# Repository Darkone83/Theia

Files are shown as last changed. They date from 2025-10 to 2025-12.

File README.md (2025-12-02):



<div align=center>
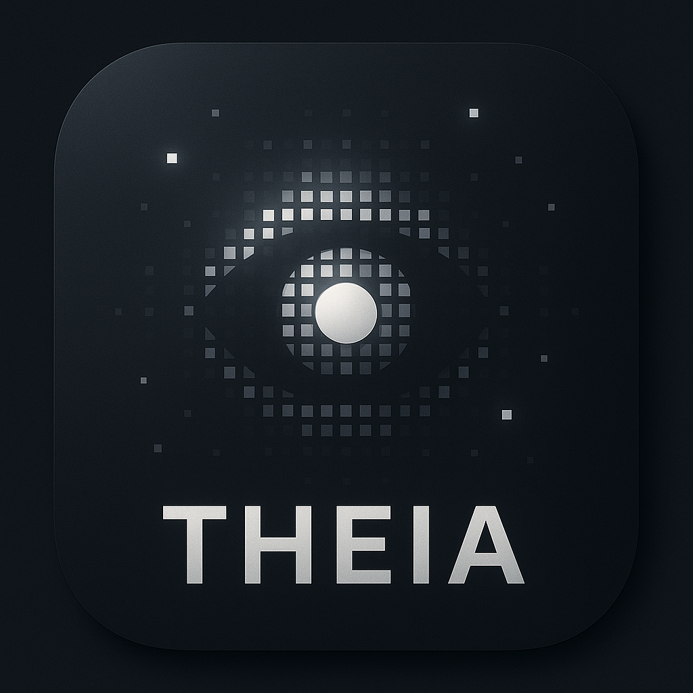
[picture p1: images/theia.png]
  

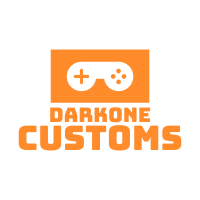
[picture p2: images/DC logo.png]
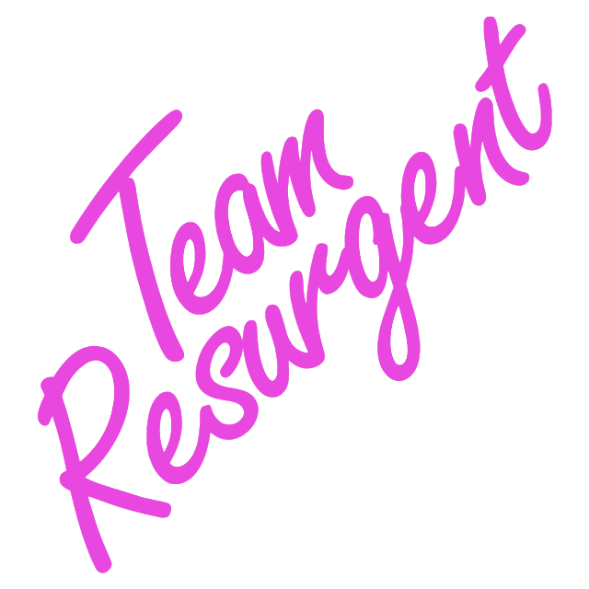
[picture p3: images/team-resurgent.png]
  
</div>

# Theia – OLED Web Emulator for Original Xbox

A Wi-Fi enabled ESP32-S3 emulator for the Xbox LCD display output.

## Overview

Theia is a lightweight firmware for the ESP32-S3 that emulates the Original Xbox 20x4 OLED/HD44780 display. It provides a browser-based LCD viewer, Wi-Fi setup portal, OTA firmware updates, and UDP/SSE LCD state streaming for PC or Mobile apps.

## Features

### Wi-Fi Setup Portal
- Connect to Wi-Fi
- Forget or update credentials
- Auto portal mode when no credentials are saved

### 20x4 OLED / LCD Emulation
- Emulates a US2066-compatible display at I2C address 0x3C
- Supports HD44780 commands and data
- Tracks cursor and row content
- Can be toggled on or off at runtime

### Web-Based LCD Viewer
Live LCD preview available at:
  /emu

JSON snapshot available at:

  /emu/state

### OTA Firmware Updates
Upload new firmware (.bin) at:

  /ota

### RGB Status LED
Indicates:
- Booting
- Wi-Fi connected
- Portal mode
- Wi-Fi failure
- UDP transmit activity

---

Download on the App Store (https://apps.apple.com/us/app/theia-oled-viewer/id6755984567)

## Purchase:

OLED Emulator module: Darkone Customs (coming soon!)

OLED kit: Dakrone Customs (coming soon!)

---

## Compiling the Firmware

1. Install **Arduino IDE 2.x**).
2. Install the **ESP32 board package**:
   - Arduino: Boards Manager → search for "esp32" → install `esp32 by Espressif Systems`
   - PlatformIO: Use the `esp32-s3` platform
3. Select the correct board:
   - `ESP32S3 Dev Module` (or your S3 variant)
4. Set the USB mode:
   - Tools → USB Mode → USB-CDC On Boot: **Enabled**
5. Open the `OLED_EMU.ino`, or `OLED_EMU_US2066.ino` file.
6. Ensure required libraries are installed:
   - ESPAsyncWebServer  
   - AsyncTCP  
   - ArduinoJson
7. Connect your ESP32-S3 board via USB.
8. Click **Upload** to compile and flash the firmware.

If compilation fails, verify the board package version and that ESPAsyncWebServer is the S3-compatible version.

---

## Hardware Installation

Transmitter:

Its recommented to wire directly to the LPC if your XBOX and to keep the wire runs as short as possible

| Pin | Transmiter | XBOX LPC |
|-----|---|---|
|  1  | 5V | 5V Pin 6 |
|  2  | GND | GND Pin 2 or 12 |
|  3  | 3.3V | 3.3V Pin 9 or 13 |
|  4  | SDA | SDA Pin 14 |
|  5  | SCL | SCL Pin 13 |

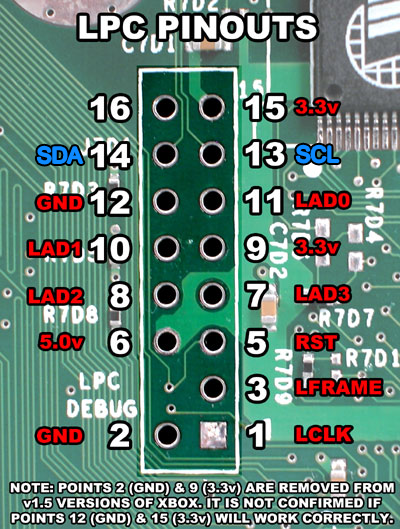
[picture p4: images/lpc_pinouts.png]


Reciever:

**Notes:** IF getting your OWN PCB's made select 1.0mm thickness for the US2066 backpack; otherwise, you may have fitment issues. This os only compatable with the NewHaven Display:  NHD-0420CW

Solder your backpack to the display, then connect 5V and GND to the controller port

When inserting into the case please take note of the TPU spacer placement

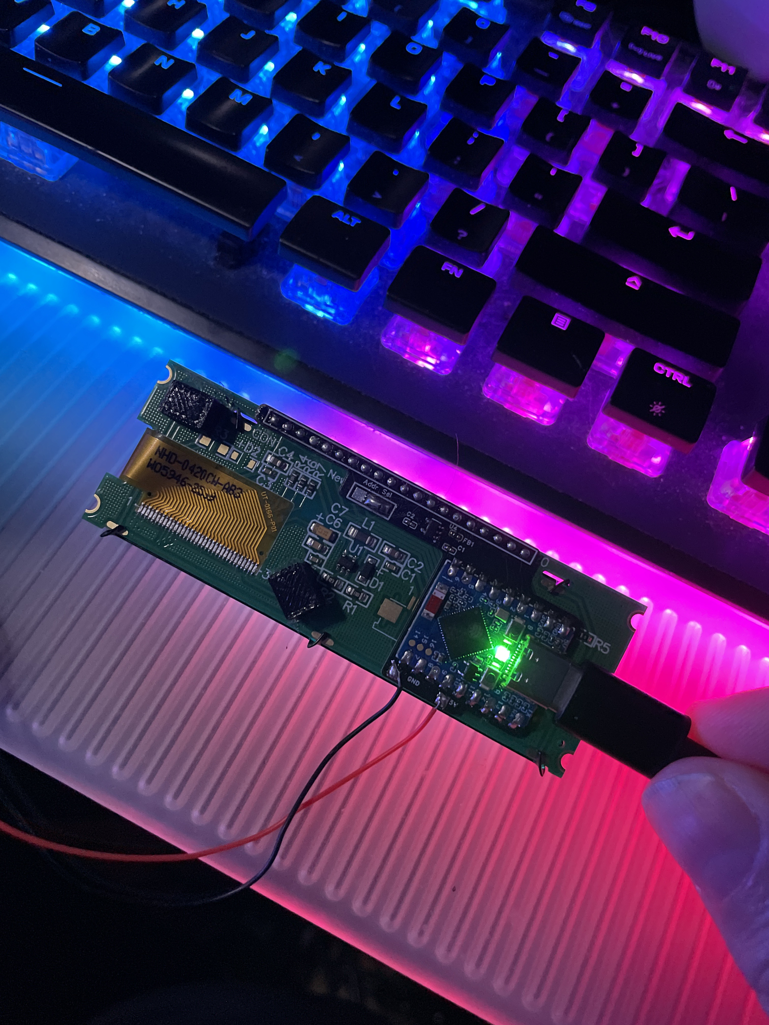
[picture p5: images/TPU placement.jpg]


## Getting Started

1. Flash the ESP32-S3 with the firmware.
2. Power the device. It starts in setup mode if Wi-Fi is not configured.
3. Connect to the access point:
   Type D OLED EMU Setup
4. Open a browser and go to:
   http://oledemu.local, or http://192.168.4.1 for the Transmitter, for the Receiver go to: http://oledemurec.local, ot http://192.168.4.1
5. Save Wi-Fi credentials.
6. After connecting:
   Web Emulator: http://oledemu.local/emu
   JSON State:   http://oledemu.local/emu/state
   OTA Update:   http://oledemu.local/ota

### XBOX Settings

PrometheOS:

Select SMBUS, HD47880 and set address to 0x3C (all other settings can be left alone)

Cerbios:

Select SMBUS, HD47880 and set address to 0x3C (all other settings can be left alone)

XBMC4Gamers:

Select SMBUS, HD47880 and set address to 0x3C (all other settings can be left alone)

## UDP Output

LCD state is broadcast as JSON over UDP on port 35182 following the Type-D viewer format.

## Compatibility

- Original Xbox (all revisions)
- PrometheOS / HD44780 LCD systems
- Type-D Viewer (PC)
- Theia (iOS / Android)

## Known Good Boards

- ESP32-S3 DevKit
- Waveshare ESP32-S3 LCD boards
- Standard S3 Mini modules

## Credits

Developed by Darkone83 / Team Resurgent.

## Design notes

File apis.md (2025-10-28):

# Theia OLED Emulator — APIs

This document lists the public C++ APIs and HTTP/UDP interfaces exposed by the firmware modules present in the provided sources (`lcd_monitor`, `web_emu`, `wifimgr`, `led_stat`).

---

## Module: `lcd_monitor`

### Purpose
Emulates a US2066/HD44780-compatible **20×4** OLED at I²C address **0x3C**, tracks DDRAM/cursor state, and broadcasts snapshots of the screen over UDP as JSON.

### C++ API
```cpp
namespace LCDMonitor {
  void begin(int sda_pin, int scl_pin);
  void loop();

  void broadcastDisplayState(bool force = false);

  // Accessors / controls
  const LCDState& getDisplayState();
  void setEmulatorEnabled(bool enabled);
  bool isEmulatorEnabled();

  // Lifecycle helpers (present for future use)
  bool startI2CSniffer();
  void stopI2CSniffer();
  bool captureI2CTraffic();

  // Hooks (present but no-op in current build)
  struct I2CTransaction { uint8_t address; uint8_t data[32]; uint8_t length; uint32_t timestamp_ms; bool is_write; };
  void processI2CTransaction(const I2CTransaction& tx);
  void decodeLCDCommand(uint8_t addr, const uint8_t* data, uint8_t len);
}
```

### Key type
```cpp
struct LCDState {
  bool display_on, cursor_on, blink_on;
  uint8_t cursor_row, cursor_col;     // 0..3, 0..19
  char rows[4][21];                   // 20 chars + NUL
  uint8_t  detected_addr;             // typically 0x3C
  const char* controller_type;        // e.g., "US2066"
  bool initialized;
  uint32_t last_update_ms, packet_count;
};
```

### UDP Broadcast
- **Address**: `255.255.255.255` (broadcast)
- **Port**: `LCD_MONITOR_UDP_PORT` (constant in header; 35182 in current build)
- **Payload**: JSON (ArduinoJson-serialized), schema:
```json
{
  "type": "lcd20x4",
  "mode": "US2066",
  "addr": "0x3C",
  "disp": true,
  "cur": false,
  "blink": false,
  "cursor": { "r": 0, "c": 0 },
  "rows": [
    "Theia OLED Emulator",
    "Code:   Darkone83   ",
    "Team Resurgent      ",
    "(c) 2025            "
  ]
}
```
Notes:
- `rows` is always **4 strings**, each padded/truncated to **20** printable ASCII characters.
- A heartbeat and a short boot **burst** are emitted; otherwise updates are sent on content change (state hash).

---

## Module: `web_emu`

### Purpose
Serves the in-browser OLED emulator and exposes a JSON snapshot endpoint and an **SSE** stream for live updates.

### C++ API
```cpp
namespace WebEmu {
  void begin();
  void loop();
}
```

### HTTP Endpoints
- **GET `/emu`** — Web UI (HTML/JS/CSS).
- **GET `/emu/state`** — Current display state as JSON (subset of UDP schema; includes `type`, `disp`, `cur`, `blink`, `cursor`, `rows`).  
  Example:
  ```json
  {
    "type":"lcd20x4",
    "disp":true, "cur":false, "blink":false,
    "cursor":{"r":0,"c":0},
    "rows":["Theia OLED Emulator","Code:   Darkone83   ","Team Resurgent      ","(c) 2025            "]
  }
  ```
- **SSE `/emu/events`** — Server-Sent Events stream.  
  - Event `message`: payload is the same JSON snapshot as `/emu/state`.
  - Periodic keep-alives (`event: ka`) when idle.

### Client Notes
- UI offers **Skin**, **Pixel mode**, **Contrast** controls. It fetches `/emu/state` on load and subscribes to `/emu/events` for updates.

---

## Module: `wifimgr`

### Purpose
Captive-portal style Wi‑Fi provisioning (AP+STA), storing credentials in NVS, plus OTA upload and LCD emulator toggles.

### C++ API
```cpp
namespace WiFiMgr {
  AsyncWebServer& getServer();
  void begin();
  void loop();
  void restartPortal();
  void forgetWiFi();
  bool isConnected();
  String getStatus();
}
```

### Captive-Portal redirects
The following GET routes redirect to `/`:
```
/generate_204
/hotspot-detect.html
/redirect
/ncsi.txt
/captiveportal
```

### Wi‑Fi & Control Endpoints
- **GET `/`** — Portal page (HTML) with scan/connect UI and emulator on/off switch.
- **GET `/status`** — Text status string of current connection or portal mode.
- **GET `/scan`** — Returns `["ssid1","ssid2",...]` (deduplicated, sorted). Triggers background scan as needed.
- **GET `/connect?ssid=...&pass=...`** — Saves credentials and begins STA connection.
- **POST `/save`** — JSON body `{"ssid":"...","pass":"..."}`. Saves and begins STA connection.
- **GET `/forget`** — Clears saved credentials and returns to portal mode.
- **GET `/debug/forget`** — Same as `/forget` with extra serial logs.
- **POST `/reboot`** — Reboots the device after a short delay.

### LCD Emulator Control
- **GET `/lcd/state`** — `{ "enabled": true|false }`
- **ANY `/lcd/enable`** — Enables the I²C OLED emulator.
- **ANY `/lcd/disable`** — Disables the I²C OLED emulator (releases I²C slave).

### OTA
- **GET `/ota`** — Minimal OTA upload page (HTML with JS progress).
- **POST `/update`** — Multipart form field `firmware` (binary). On success responds `200 OK`. (No auto‑restart; use `/reboot`.)

---

## Module: `led_stat`

### Purpose
Single NeoPixel RGB LED indicating device status.

### C++ API
```cpp
enum class LedStatus { Booting, Portal, WifiConnected, WifiFailed, UdpTransmit };

namespace LedStat {
  void begin();
  void setStatus(LedStatus status);
  void loop();
}
```

### Behavior (defaults)
- `Booting` → solid white
- `Portal` → blinking purple
- `WifiConnected` → solid green
- `WifiFailed` → solid red
- `UdpTransmit` → brief activity indication (if used)

---

## Integration Cheatsheet

### Listen for screen updates (PC/receiver)
- Bind UDP socket to **port 35182**.
- Parse the JSON payload (see schema above).

### Browser client
- Initial snapshot: `GET /emu/state`
- Live updates: `EventSource('/emu/events')`

### Toggle emulator
```
GET /lcd/state
ANY /lcd/enable
ANY /lcd/disable
```

### Provision Wi‑Fi
```
GET  /scan
POST /save        body: {"ssid":"<ssid>","pass":"<pass>"}
GET  /connect?ssid=<ssid>&pass=<pass>
GET  /forget
GET  /status
```

### OTA
```
GET  /ota
POST /update   (multipart form data: firmware=<bin>)
POST /reboot
```

---

## Notes
- The emulator sanitizes non-printable characters to space (0x20) for UDP/HTTP emits.
- A small boot **burst** and periodic **keep-alives** ensure downstream listeners initialize correctly even if the screen is static.

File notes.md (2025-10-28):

# Notes

## US2066 PCB

---

Should be made @ 1.0mm to fit proeprly in the case

---

## STLs

---

TPU space is HIGHLY recommened to be made in TPU with 30% infill. Check images folder for approximate placement

---

## Required Arduino libraties

---

ArduinoJSON
ESPAsyncWebServer

---

## Arduino Boards

---

esp32 (3.3.2)

---

## Board Config

---

Parition: Default 4mb with spiffs
CDC: Enabled
Flash size: 4mb

---

## Notes

---

Tested with the WaveShare ESP32 zero and clone boards on aliexpress

---

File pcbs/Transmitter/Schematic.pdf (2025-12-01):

GND

GND

5V

XSCL
XSDA
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
XBSMB

ZX-SH1.0-5PWT

3.3V

GND

5V

XSCL | XSDA

5V 1
GND 2
3V3 3
IO1 4
IO2 5
IO3 6
IO4 7
IO5 8
IO6 9

# IO7 10 IO8 11 IO9 12 IO10 13 IO11 14 IO12 15 IO13 16 RX 17 TX 18

U1

ESP32-S3-Zero

3.3V

5V | 5VEN
GND
1uFC1 | C2 1uF

R1
100k
GND | GND

GND

VIN 1
GND 2
ON 3 | CT 4

QOD 5

VOUT 6

U2

TPS22918DBVR

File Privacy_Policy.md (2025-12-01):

Theia – Privacy Policy

Last updated: 11/27/2025

---

Overview

---

Theia respects your privacy.
This app does not collect, store, transmit, or share any personal data of any kind.

Information We Do Not Collect

Theia does not collect or process:

Personal information

Usage data

Diagnostics data

Location data

Contact information

Identifiers

Photos, media, or files

Device analytics

Advertiser data

Any data linked or not linked to you

Data Handling

The app performs all operations locally on your device.

No data is sent to external servers.

No third-party SDKs, analytics, tracking, or advertising frameworks are used.

---

Children’s Privacy

Because Theia collects no data, it is safe for users of all ages.
No information is knowingly collected from children.

---

Third-Party Access

Theia does not share any information with third parties because no information is collected at all.

---

Changes to This Policy

If the privacy policy is ever updated, changes will be posted within the app and on the associated website or repository. The app will continue to collect no data unless explicitly stated in a future revision.

---

Contact

If you have questions about this Privacy Policy, you can contact us:

Darkone Customs

Email: darkonecustoms@gmail.com

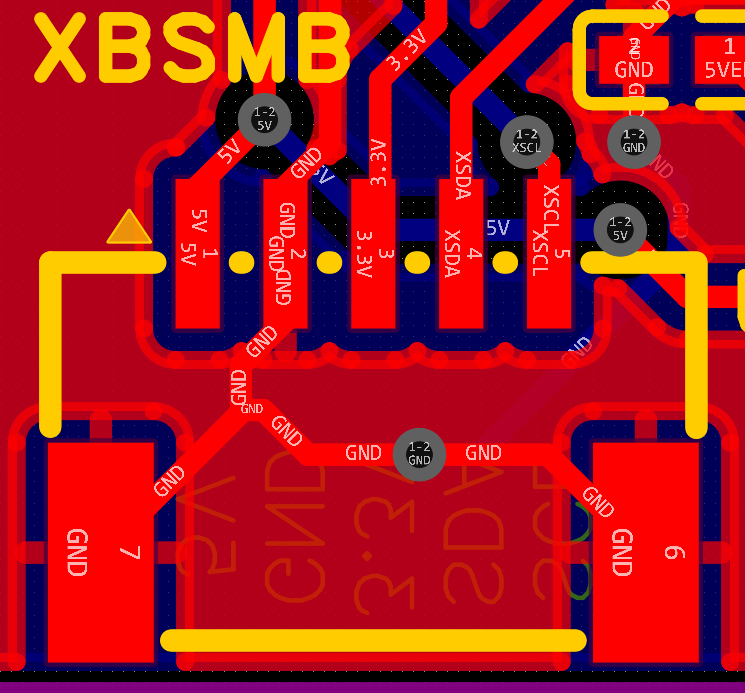
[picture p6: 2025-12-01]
images/pins.png

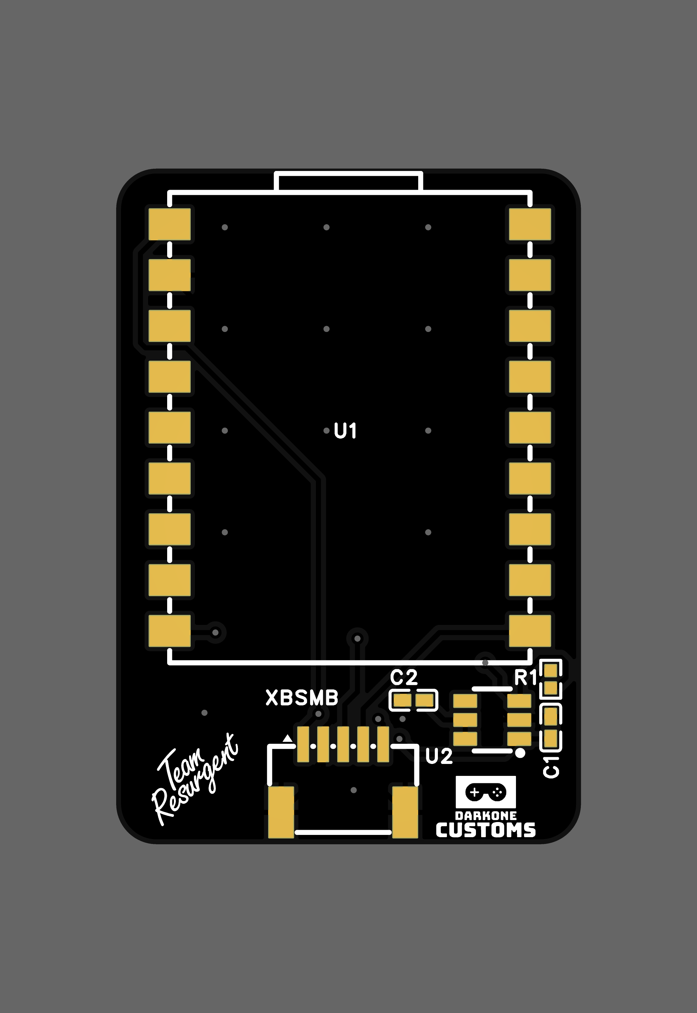
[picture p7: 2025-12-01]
images/2D Front Transmitter.png

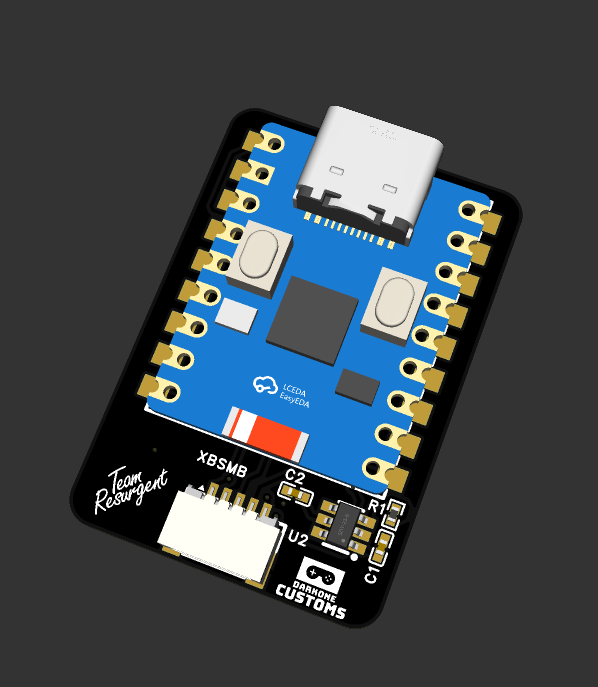
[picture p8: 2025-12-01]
images/3D Front Transmitter.png

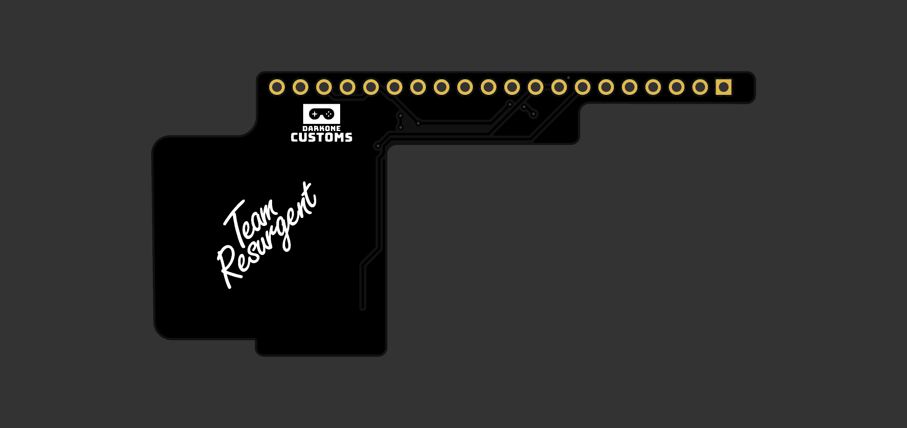
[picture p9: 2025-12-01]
images/2D Back US2066 Backpack.png

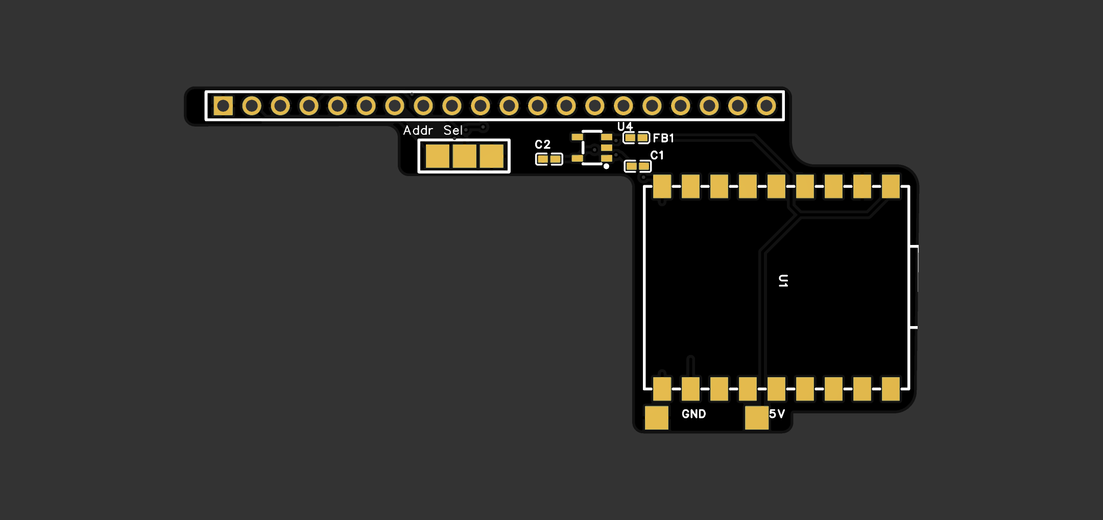
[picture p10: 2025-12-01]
images/2D Front US2066 Backpack.png

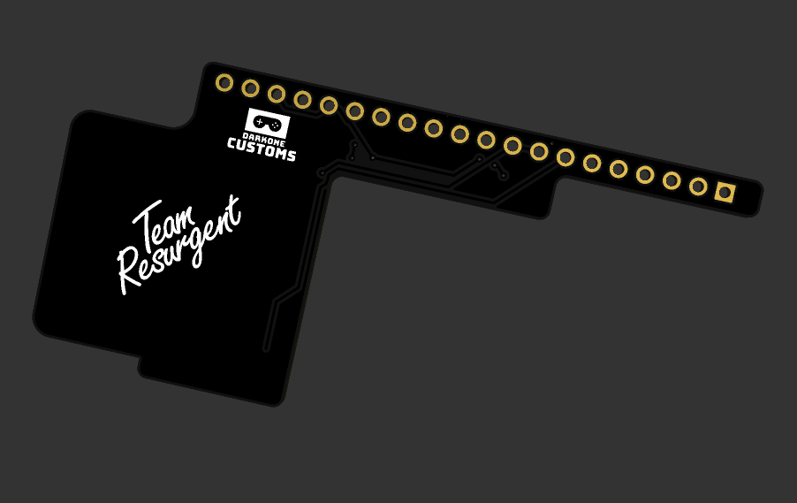
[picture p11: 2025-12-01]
images/3D Back US2066 Backpack.png

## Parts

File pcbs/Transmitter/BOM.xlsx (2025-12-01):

No. | Quantity | Comment | Designator | Footprint | Value | Manufacturer Part | Manufacturer | Supplier Part | Supplier
1 | 2 | 1uF | C1,C2 | C0402 | 1uF | CL05A105KO5NNNC | SAMSUNG(三星) | C29266 | LCSC
2 | 1 | 100kΩ | R1 | R0402 | 100kΩ | RC0402FR-07100KL | YAGEO(国巨) | C60491 | LCSC
3 | 1 | ESP32-S3-Zero | U1 | COMM-SMD_18P-P2.54-L23.5-W18.0-TL |  | ESP32-S3-Zero |  | C9900152785 | LCSC
4 | 1 | TPS22918DBVR | U2 | SOT-23-6_L2.9-W1.6-P0.95-LS2.8-BR |  | TPS22918DBVR | TI(德州仪器) | C131941 | LCSC
5 | 1 | ZX-SH1.0-5PWT | XBSMB | CONN-SMD_5P-P1.00_MEGASTAR_ZX-SH1.0-5PWT |  | ZX-SH1.0-5PWT | Megastar(兆星) | C7430447 | LCSC

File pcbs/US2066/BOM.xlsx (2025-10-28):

No. | Quantity | Comment | Designator | Footprint | Value | Manufacturer Part | Manufacturer | Supplier Part | Supplier
1 | 5 | Test-Point | 5V,GND,TP1,TP2,TP3 | Test-Point-0.5mm
2 | 2 | 1uF | C1,C2 | C0402 | 1uF | CL05A105KO5NNNC | SAMSUNG(三星) | C29266 | LCSC
3 | 1 | CBM100505U201T | FB1 | L0402 |  | CBM100505U201T | FH(风华) | C394402 | LCSC
4 | 1 | ESP32-S3-Zero | U1 | COMM-SMD_18P-P2.54-L23.5-W18.0-TL |  | ESP32-S3-Zero |  | C9900152785 | LCSC
5 | 1 | XC6227C331MR-G | U4 | SOT-25-5 |  | XC6227C331MR-G | TOREX(特瑞仕) | C216640 | LCSC

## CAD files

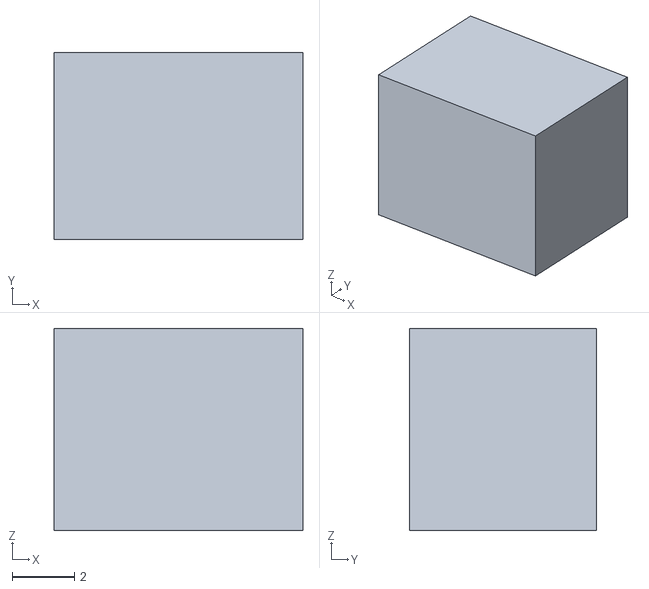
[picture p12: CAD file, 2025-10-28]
STL/TPU Spacer Cube.stl
8.00 x 6.00 x 6.50

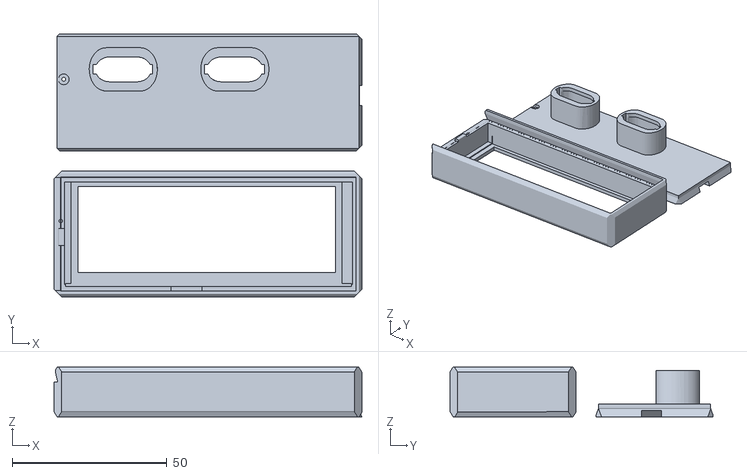
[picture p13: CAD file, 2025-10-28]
STL/US2066 Shell.stl
99.4 x 84.9 x 16.0

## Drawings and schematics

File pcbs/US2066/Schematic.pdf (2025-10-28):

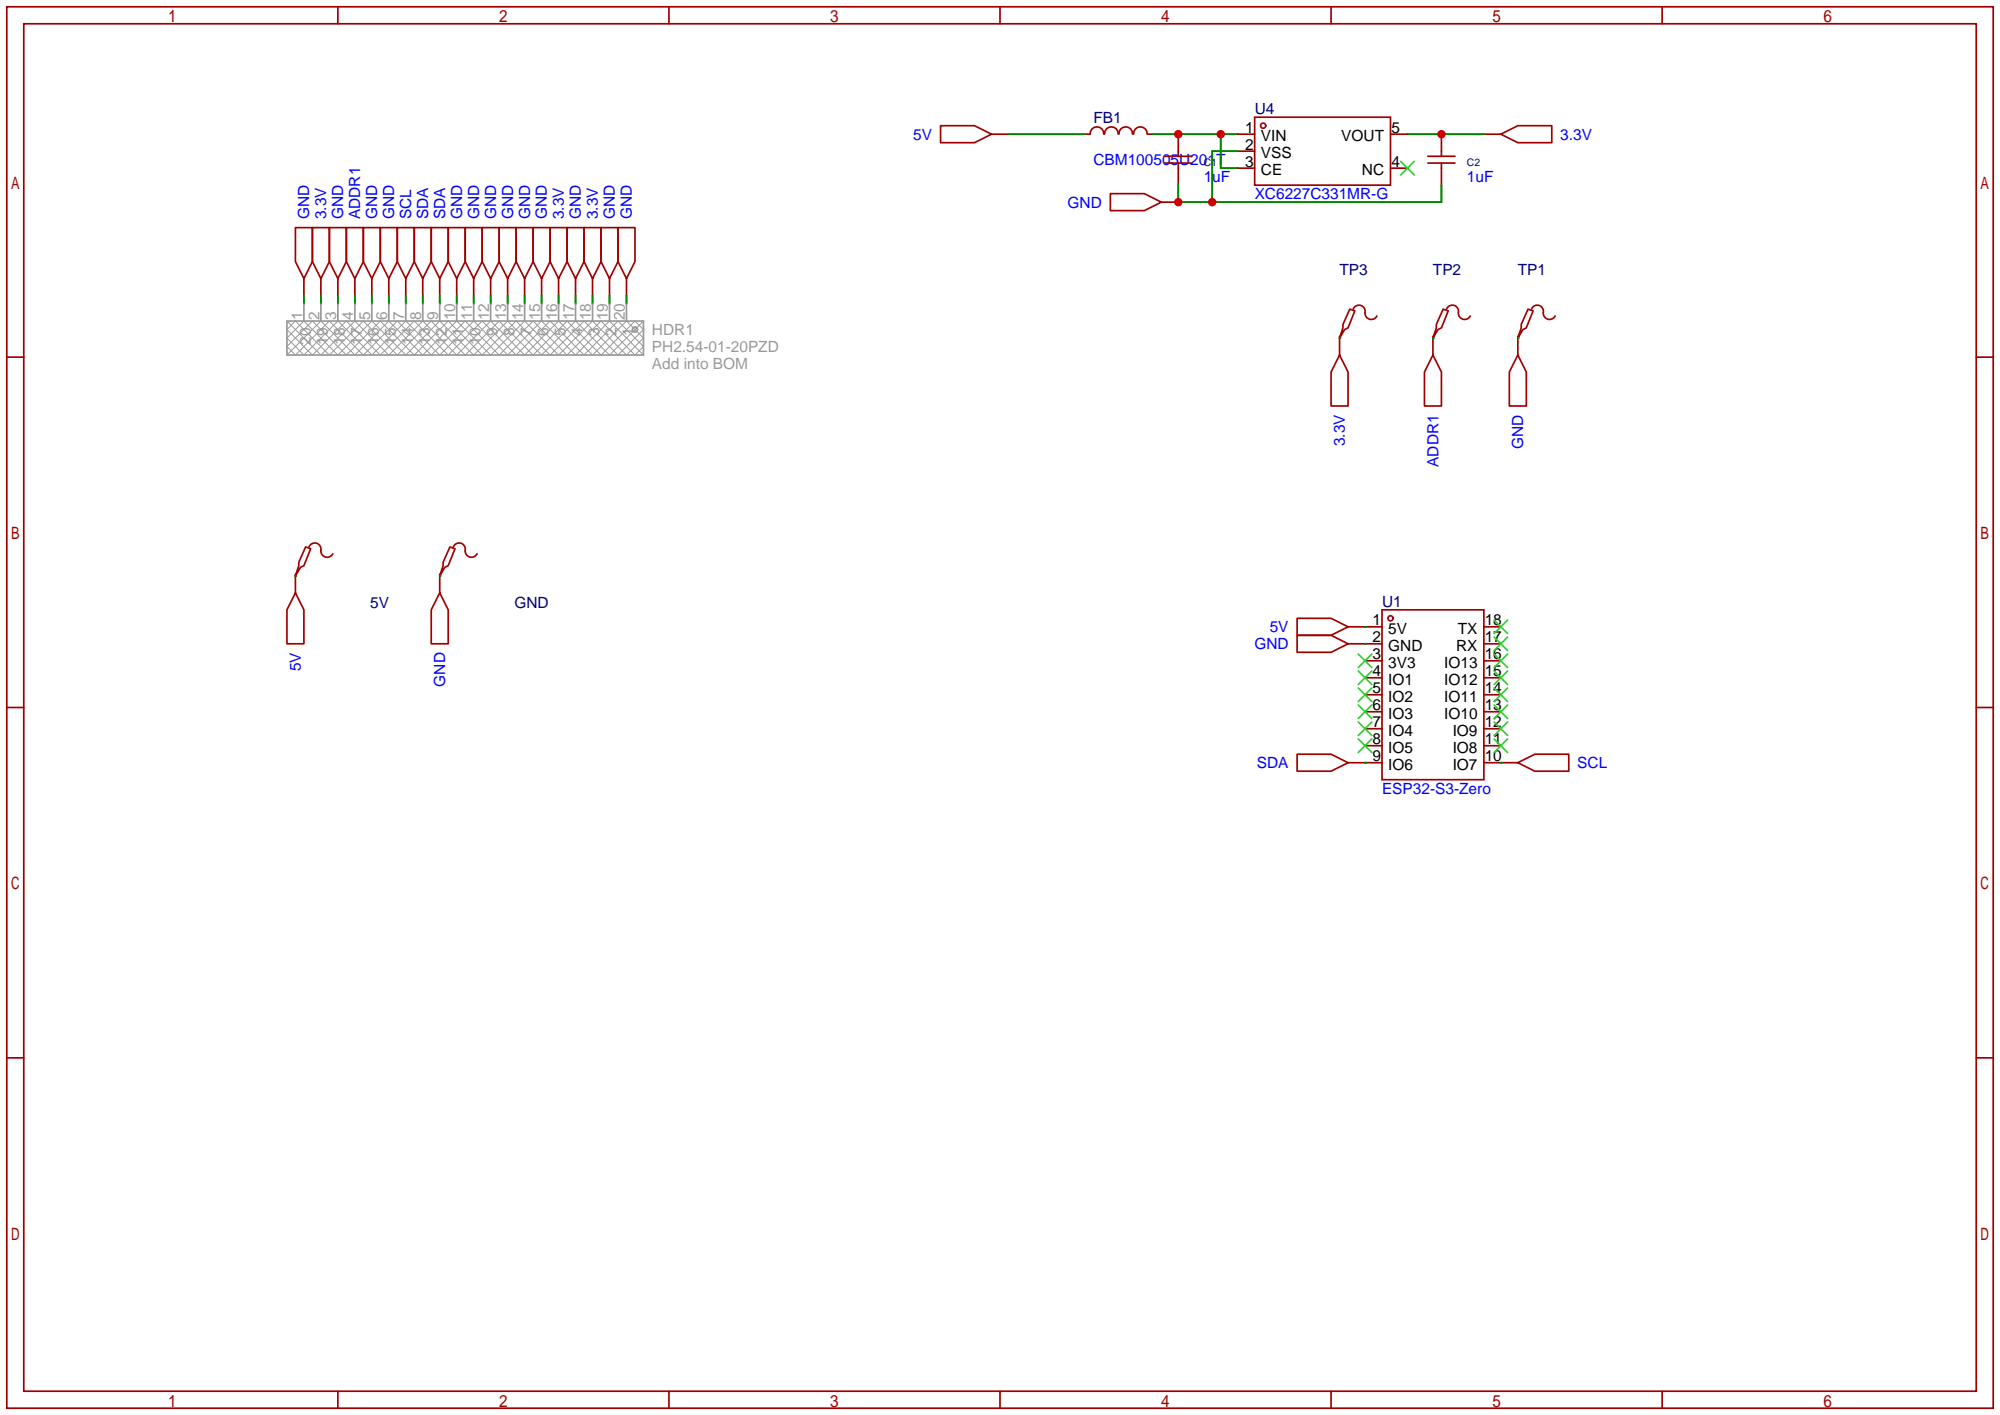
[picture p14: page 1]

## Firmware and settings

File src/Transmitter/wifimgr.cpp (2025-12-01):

#include "wifimgr.h"
#include <WiFi.h>
#include <ESPAsyncWebServer.h>
#include <Preferences.h>
#include <DNSServer.h>
#include "led_stat.h"
#include <vector>
#include "esp_wifi.h"
#include <Update.h> // For OTA
#include "lcd_monitor.h" // <-- for emulator enable/disable

static AsyncWebServer server(80);
namespace WiFiMgr {

static String ssid, password;
static Preferences prefs;
static DNSServer dnsServer;
static std::vector<String> lastScanResults;

enum class State { IDLE, CONNECTING, CONNECTED, PORTAL };
static State state = State::PORTAL;

static int connectAttempts = 0;
static const int maxAttempts = 10;
static unsigned long lastAttempt = 0;
static unsigned long retryDelay = 3000;

AsyncWebServer& getServer() {
    return server;
}

static void setAPConfig() {
    WiFi.softAPConfig(
        IPAddress(192, 168, 4, 1),
        IPAddress(192, 168, 4, 1),
        IPAddress(255, 255, 255, 0)
    );
}

void loadCreds() {
    prefs.begin("wifi", true);
    ssid = prefs.getString("ssid", "");
    password = prefs.getString("pass", "");
    prefs.end();
}

void saveCreds(const String& s, const String& p) {
    prefs.begin("wifi", false);
    prefs.putString("ssid", s);
    prefs.putString("pass", p);
    prefs.end();
}

void clearCreds() {
    prefs.begin("wifi", false);
    prefs.remove("ssid");
    prefs.remove("pass");
    prefs.end();
}

static String htmlSwitch(bool on) {
    String checked = on ? "checked" : "";
    return String() +
        "<label class='switch'>"
        "<input id='emuToggle' type='checkbox' " + checked + " onchange='toggleEmu(this.checked)'>"
        "<span class='slider round'></span>"
        "</label>";
}

void startPortal() {
    WiFi.disconnect(true);
    delay(100);
    setAPConfig();
    WiFi.mode(WIFI_AP_STA);  // AP+STA for S3 (portal)
    delay(100);

    // Use channel 6 for iOS compatibility
    bool apok = WiFi.softAP("Type D OLED EMU Setup", "", 6, 0);
    esp_wifi_set_max_tx_power(20);
    LedStat::setStatus(LedStatus::Portal);
    Serial.printf("[WiFiMgr] softAP result: %d, IP: %s\n", apok, WiFi.softAPIP().toString().c_str());
    delay(200);

    IPAddress apIP = WiFi.softAPIP();
    dnsServer.start(53, "*", apIP);

    server.reset(); // avoid duplicate routes on restart

    // Allow cross-origin (Electron/file:// webviews)
    DefaultHeaders::Instance().addHeader("Access-Control-Allow-Origin", "*");

    server.on("/", HTTP_GET, [](AsyncWebServerRequest *request){
        const bool emuOn = LCDMonitor::isEmulatorEnabled();
        String page = R"rawliteral(
<!DOCTYPE html>
<html>
<head>
    <title>WiFi Setup</title>
    <meta name="viewport" content="width=320,initial-scale=1">
    <style>
        body {background:#111;color:#EEE;font-family:sans-serif;}
        .container {max-width:340px;margin:24px auto;background:#222;padding:2em;border-radius:12px;box-shadow:0 0 16px #0008;}
        input,select,button {width:100%;box-sizing:border-box;margin:.7em 0;padding:.6em;font-size:1.05em;border-radius:8px;border:1px solid #555;background:#111;color:#EEE;}
        .btn-primary {background:#299a2c;color:white;border-color:#299a2c;}
        .btn-danger {background:#a22;color:white;border-color:#a22;}
        .btn-ota {background:#265aa5;color:white;border-color:#265aa5;}
        .btn-web {background:#3b82f6;color:white;border-color:#3b82f6;}
        .status {margin-top:1em;font-size:.95em;}
        label {display:block;margin-top:.5em;margin-bottom:.1em;}
        .row {display:flex;gap:10px;align-items:center;}
        .row > * {flex:1;}
        .pill {display:inline-block;padding:.35em .6em;border-radius:999px;background:#333;border:1px solid #555;font-size:.85em;margin-left:6px;}
        .switch {position: relative; display: inline-block; width: 52px; height: 28px; vertical-align:middle;}
        .switch input {opacity: 0; width: 0; height: 0;}
        .slider {position: absolute; cursor: pointer; top: 0; left: 0; right: 0; bottom: 0; background-color: #555; transition: .2s; border-radius: 28px;}
        .slider:before {position: absolute; content: ""; height: 22px; width: 22px; left: 3px; bottom: 3px; background-color: white; transition: .2s; border-radius:50%;}
        input:checked + .slider {background-color: #299a2c;}
        input:checked + .slider:before {transform: translateX(24px);}
        .section {margin-top:18px;padding-top:12px;border-top:1px dashed #444;}
        .small {font-size:.9em;color:#bbb;}
    </style>
</head>
<body>
    <div class="container">
        <div style="width:100%;text-align:center;margin-bottom:1em">
            <span style="font-size:1.6em;font-weight:bold;">Type D OLED Emulator Setup</span>
        </div>

        <div class="section">
            <div class="row" style="justify-content:space-between">
                <div style="flex:unset"><b>LCD Emulator</b><span id="emuState" class="pill">...</span></div>
                <div style="flex:unset" id="emuSwitchHolder">__EMU_SWITCH__</div>
            </div>
            <div class="small">Toggle the US2066 emulator (I²C slave at 0x3C) on/off without reboot. Disabling releases the I²C bus.</div>
        </div>

        <div class="section">
            <form id="wifiForm" onsubmit="return false;">
                <label>WiFi Network</label>
                <select id="ssidDropdown" style="margin-bottom:1em;">
                    <option value="">Please select a network</option>
                </select>
                <input type="text" id="ssid" placeholder="SSID" style="margin-bottom:1em;">
                <label>Password</label>
                <input type="password" id="pass" placeholder="WiFi Password">
                <div class="row">
                    <button type="button" onclick="save()" class="btn-primary">Connect & Save</button>
                    <button type="button" onclick="forget()" class="btn-danger">Forget WiFi</button>
                </div>
                <div class="row">
                    <button type="button" onclick="window.location='/ota'" class="btn-ota">OTA Update</button>
                    <button type="button" onclick="window.location='/emu'" class="btn-web">Web View</button>
                </div>
                <div class="row">
                    <button type="button" onclick="fetch('/udp/ping',{method:'POST'}).then(r=>r.text()).then(t=>alert(t)).catch(()=>alert('Ping failed'))" class="btn-web">Test UDP Ping</button>
                </div>
            </form>
            <div class="status" id="status">Status: ...</div>
        </div>
    </div>
    <script>
        function setEmuStateTag(on){
            const tag = document.getElementById('emuState');
            tag.textContent = on ? 'ENABLED' : 'DISABLED';
            tag.style.background = on ? '#164b18' : '#4b1616';
            tag.style.borderColor = on ? '#299a2c' : '#a22';
        }
        function fetchEmuState(){
            fetch('/lcd/state').then(r=>r.json()).then(j=>{
                setEmuStateTag(!!j.enabled);
                const toggle = document.getElementById('emuToggle');
                if (toggle) toggle.checked = !!j.enabled;
            }).catch(()=>{});
        }
        function toggleEmu(on){
            fetch(on ? '/lcd/enable' : '/lcd/disable', {method:'POST'})
                .then(()=>fetchEmuState());
        }

        function uniq(arr){ return [...new Set(arr.filter(s=>s && s.trim().length))]; }
        let scanning=false;
        function scan() {
            if (scanning) return; scanning=true;
            fetch('/scan').then(r => r.json()).then(list => {
                list = uniq(list).sort((a,b)=>a.localeCompare(b));
                let dropdown = document.getElementById('ssidDropdown');
                dropdown.innerHTML = '';
                let defaultOpt = document.createElement('option');
                defaultOpt.value = '';
                defaultOpt.text = 'Please select a network';
                dropdown.appendChild(defaultOpt);
                list.forEach(ssid => {
                    let opt = document.createElement('option');
                    opt.value = ssid;
                    opt.text = ssid;
                    dropdown.appendChild(opt);
                });
                dropdown.onchange = function() {
                    document.getElementById('ssid').value = dropdown.value;
                };
            }).catch(() => {
                let dropdown = document.getElementById('ssidDropdown');
                dropdown.innerHTML = '';
                let opt = document.createElement('option');
                opt.value = '';
                opt.text = 'Scan failed';
                dropdown.appendChild(opt);
            }).finally(()=>{ scanning=false; });
        }
        setInterval(scan, 3000);
        window.onload = function(){
            scan();
            fetchEmuState();
        };
        function save() {
            let ssid = document.getElementById('ssid').value;
            let pass = document.getElementById('pass').value;
            fetch('/save', {
                method: 'POST',
                headers: {'Content-Type': 'application/json'},
                body: JSON.stringify({ssid:ssid,pass:pass})
            }).then(r => r.text()).then(t => {
                document.getElementById('status').innerText = t;
            });
        }
        function forget() {
            fetch('/forget').then(r => r.text()).then(t => {
                document.getElementById('status').innerText = t;
                document.getElementById('ssid').value = '';
                document.getElementById('pass').value = '';
            });
        }
        document.getElementById('emuSwitchHolder').innerHTML = `)rawliteral";
        page += htmlSwitch(emuOn);
        page += R"rawliteral(`.replace('__EMU_SWITCH__','');
    </script>
</body>
</html>
        )rawliteral";
        request->send(200, "text/html", page);
    });

    // === OTA PAGE ===
    server.on("/ota", HTTP_GET, [](AsyncWebServerRequest *request){
        String page = R"rawliteral(
<!DOCTYPE html>
<html>
<head>
    <title>OTA Update</title>
    <meta name="viewport" content="width=320,initial-scale=1">
    <style>
        body {background:#111;color:#EEE;font-family:sans-serif;}
        .container {max-width:360px;margin:24px auto;background:#222;padding:2em;border-radius:12px;box-shadow:0 0 16px #0008;}
        input[type=file],button {width:100%;box-sizing:border-box;margin:.7em 0;padding:.6em;font-size:1.05em;border-radius:8px;border:1px solid #555;background:#111;color:#EEE;}
        .btn {background:#265aa5;color:white;border-color:#265aa5;}
        .status {margin-top:1em;font-size:.95em;}
        .barWrap {background:#111;border:1px solid #555;border-radius:8px;overflow:hidden;height:16px;margin-top:.5em}
        .bar {height:100%;width:0%;}
    </style>
</head>
<body>
    <div class="container">
        <h2>OTA Update</h2>
        <input id="fw" type="file" accept=".bin">
        <button class="btn" onclick="doUpload()">Upload & Flash</button>
        <div class="barWrap"><div id="bar" class="bar"></div></div>
        <div id="pct" class="status">0%</div>
        <div id="otaStatus" class="status"></div>
        <div class="row">
            <button class="btn" onclick="window.location='/'" style="margin-top:14px;">Back to WiFi Setup</button>
            <button class="btn" onclick="fetch('/reboot',{method:'POST'}).then(()=>{document.getElementById('otaStatus').innerText='Rebooting...';})" style="margin-top:14px;">Reboot Now</button>
        </div>
    </div>
    <script>
        function doUpload(){
            const f = document.getElementById('fw').files[0];
            if(!f){ alert('Choose a .bin first'); return; }
            const xhr = new XMLHttpRequest();
            xhr.open('POST','/update',true);
            xhr.upload.onprogress = (e)=>{
                if(e.lengthComputable){
                    const p = Math.round((e.loaded/e.total)*100);
                    document.getElementById('bar').style.width = p + '%';
                    document.getElementById('bar').style.background = p>=100 ? '#299a2c' : '#265aa5';
                    document.getElementById('pct').innerText = p + '%';
                }
            };
            xhr.onreadystatechange = ()=>{
                if(xhr.readyState===4){
                    if(xhr.status===200){
                        document.getElementById('otaStatus').innerText = 'Upload complete. Flash OK.';
                    } else {
                        document.getElementById('otaStatus').innerText = 'Upload finished with status ' + xhr.status;
                    }
                }
            };
            const form = new FormData();
            form.append('firmware', f, f.name);
            xhr.send(form);
        }
    </script>
</body>
</html>
        )rawliteral";
        request->send(200, "text/html", page);
    });

    // === OTA FIRMWARE UPLOAD HANDLER (chunked) ===
    server.on("/update", HTTP_POST,
        [](AsyncWebServerRequest *request){},
        [](AsyncWebServerRequest *request, String filename, size_t index, uint8_t *data, size_t len, bool final) {
            static bool updateError = false;
            if (!index) {
                Serial.printf("[OTA] Start update: %s (streaming)\n", filename.c_str());
                updateError = false;
                if (!Update.begin(UPDATE_SIZE_UNKNOWN)) {
                    Update.printError(Serial);
                    updateError = true;
                }
            }
            if (!updateError && !Update.hasError()) {
                size_t written = Update.write(data, len);
                if (written != len) {
                    Update.printError(Serial);
                    updateError = true;
                }
            }
            if (final) {
                bool ok = (!updateError && Update.end(true));
                if (!ok) {
                    Update.printError(Serial);
                    request->send(200, "text/plain", "Update processed, but reported an error: " + String(Update.errorString()));
                } else {
                    request->send(200, "text/plain", "OK");
                    Serial.println("[OTA] Update success (no auto-restart). Use /reboot or power-cycle.");
                }
            }
        }
    );

    // Explicit reboot endpoint
    server.on("/reboot", HTTP_POST, [](AsyncWebServerRequest *request){
        request->send(200, "text/plain", "Rebooting...");
        Serial.println("[WiFiMgr] Reboot requested via /reboot");
        delay(200);
        ESP.restart();
    });

    // Status
    server.on("/status", HTTP_GET, [](AsyncWebServerRequest *request){
        String stat;
        if (WiFi.status() == WL_CONNECTED)
            stat = "Connected to " + WiFi.SSID() + " - IP: " + WiFi.localIP().toString();
        else if (state == State::CONNECTING)
            stat = "Connecting to " + ssid + "...";
        else
            stat = "In portal mode";
        request->send(200, "text/plain", stat);
    });

    // Connect via GET (legacy)
    server.on("/connect", HTTP_GET, [](AsyncWebServerRequest *request){
        String ss, pw;
        if (request->hasParam("ssid")) ss = request->getParam("ssid")->value();
        if (request->hasParam("pass")) pw = request->getParam("pass")->value();
        if (ss.length() == 0) {
            request->send(400, "text/plain", "SSID missing");
            return;
        }
        saveCreds(ss, pw);
        ssid = ss;
        password = pw;
        state = State::CONNECTING;
        connectAttempts = 1;
        WiFi.mode(WIFI_AP_STA);
        delay(100);
        WiFi.begin(ssid.c_str(), password.c_str());
        request->send(200, "text/plain", "Connecting to: " + ssid);
    });

    // Scan with caching + de-dup
    server.on("/scan", HTTP_GET, [](AsyncWebServerRequest *request){
        int n = WiFi.scanComplete();
        if (n == -2) {
            WiFi.scanNetworks(true, true);
        } else if (n >= 0) {
            lastScanResults.clear();
            lastScanResults.reserve(n);
            for (int i = 0; i < n; ++i) {
                String s = WiFi.SSID(i);
                if (s.length()) lastScanResults.push_back(s);
            }
            WiFi.scanDelete();
            WiFi.scanNetworks(true, true);
        }
        std::sort(lastScanResults.begin(), lastScanResults.end());
        lastScanResults.erase(std::unique(lastScanResults.begin(), lastScanResults.end()), lastScanResults.end());
        String json = "[";
        for (size_t i = 0; i < lastScanResults.size(); ++i) {
            if (i) json += ",";
            json += "\"" + lastScanResults[i] + "\"";
        }
        json += "]";
        request->send(200, "application/json", json);
    });

    server.on("/forget", HTTP_GET, [](AsyncWebServerRequest *request){
        clearCreds();
        ssid = ""; password = "";
        WiFi.disconnect();
        state = State::PORTAL;
        request->send(200, "text/plain", "WiFi credentials cleared.");
    });

    server.on("/debug/forget", HTTP_GET, [](AsyncWebServerRequest *request){
        clearCreds();
        ssid = "";
        password = "";
        WiFi.disconnect(true);
        state = State::PORTAL;
        Serial.println("[DEBUG] WiFi credentials cleared via /debug/forget");
        request->send(200, "text/plain", "WiFi credentials cleared (debug).");
    });

    // Proper POST JSON body for ESPAsyncWebServer (Arduino 3.2.0)
    server.on("/save", HTTP_POST,
        [](AsyncWebServerRequest *request){},
        NULL,
        [](AsyncWebServerRequest *request, uint8_t *data, size_t len, size_t, size_t) {
            String body; body.reserve(len);
            for (size_t i = 0; i < len; i++) body += (char)data[i];
            int ssidStart = body.indexOf("\"ssid\":\"") + 8;
            int ssidEnd   = body.indexOf("\"", ssidStart);
            int passStart = body.indexOf("\"pass\":\"") + 8;
            int passEnd   = body.indexOf("\"", passStart);
            String newSsid = (ssidStart >= 8 && ssidEnd > ssidStart) ? body.substring(ssidStart, ssidEnd) : "";
            String newPass = (passStart >= 8 && passEnd > passStart) ? body.substring(passStart, passEnd) : "";
            if (newSsid.length() == 0) {
                request->send(400, "text/plain", "SSID missing");
                return;
            }
            saveCreds(newSsid, newPass);
            ssid = newSsid;
            password = newPass;
            state = State::CONNECTING;
            connectAttempts = 1;
            WiFi.begin(newSsid.c_str(), newPass.c_str());
            request->send(200, "text/plain", "Connecting to: " + newSsid);
            Serial.printf("[WiFiMgr] Received new creds. SSID: %s\n", newSsid.c_str());
        }
    );

    // ---------- LCD Emulator control ----------
    server.on("/lcd/state", HTTP_GET, [](AsyncWebServerRequest *request){
        bool en = LCDMonitor::isEmulatorEnabled();
        String j = String("{\"enabled\":") + (en ? "true" : "false") + "}";
        request->send(200, "application/json", j);
    });
    server.on("/lcd/enable", HTTP_ANY, [](AsyncWebServerRequest *request){
        LCDMonitor::setEmulatorEnabled(true);
        request->send(200, "text/plain", "LCD emulator enabled");
    });
    server.on("/lcd/disable", HTTP_ANY, [](AsyncWebServerRequest *request){
        LCDMonitor::setEmulatorEnabled(false);
        request->send(200, "text/plain", "LCD emulator disabled");
    });

    // ---------- UDP test (force a packet now) ----------
    server.on("/udp/ping", HTTP_POST, [](AsyncWebServerRequest *request){
        LCDMonitor::broadcastDisplayState(true);
        request->send(200, "text/plain", "UDP test packet sent");
    });

    auto cp = [](AsyncWebServerRequest *r){
        r->send(200, "text/html", "<meta http-equiv='refresh' content='0; url=/' />");
    };
    server.on("/generate_204", HTTP_GET, cp);
    server.on("/hotspot-detect.html", HTTP_GET, cp);
    server.on("/redirect", HTTP_GET, cp);
    server.on("/ncsi.txt", HTTP_GET, cp);
    server.on("/captiveportal", HTTP_GET, cp);
    server.onNotFound(cp);

    server.begin();
    state = State::PORTAL;
}

void stopPortal() {
    dnsServer.stop();
}
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
void loop() {
    dnsServer.processNextRequest();
    if (state == State::CONNECTING) {
        if (WiFi.status() == WL_CONNECTED) {
            state = State::CONNECTED;
            dnsServer.stop();
            Serial.println("[WiFiMgr] WiFi connected.");
            Serial.print("[WiFiMgr] IP Address: ");
            Serial.println(WiFi.localIP());
            LedStat::setStatus(LedStatus::WifiConnected);

            // ---- IMPORTANT: Legacy-like behavior: disable AP after STA connects ----
            WiFi.softAPdisconnect(true);
            WiFi.mode(WIFI_STA);
            Serial.println("[WiFiMgr] AP disabled; running STA-only");

        } else if (millis() - lastAttempt > retryDelay) {
            connectAttempts++;
            if (connectAttempts >= maxAttempts) {
                state = State::PORTAL;
                startPortal();
                LedStat::setStatus(LedStatus::WifiFailed);
            } else {
                WiFi.disconnect();
                WiFi.begin(ssid.c_str(), password.c_str());
                lastAttempt = millis();
            }
        }
    }
}

void restartPortal() {
    startPortal();
}

void forgetWiFi() {
    clearCreds();
    startPortal();
}

void forgetWiFiFromSerial() {
    clearCreds();
    WiFi.disconnect(true);
    ssid = "";
    password = "";
    Serial.println("[SerialCmd] WiFi credentials forgotten.");
    startPortal();
}

bool isConnected() {
    return WiFi.status() == WL_CONNECTED;
}

String getStatus() {
    if (isConnected()) return "Connected to: " + ssid;
    if (state == State::CONNECTING) return "Connecting to: " + ssid;
    return "Not connected";
}

} // namespace WiFiMgr

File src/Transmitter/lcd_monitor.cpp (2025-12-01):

// lcd_monitor.cpp
//
// HD44780 LCD Slave Device for Original Xbox Type-D firmware
// ESP32 presents itself as US2066/SH1122 OLED controller at address 0x3C
// Handles PrometheOS I2C protocol: [CONTROL_BYTE] [DATA_BYTE]

#include "lcd_monitor.h"
#include <Arduino.h>
#include <WiFiUdp.h>
#include <ArduinoJson.h>
#include <Wire.h>

// Private state
static WiFiUDP lcdUdp;
static bool udp_begun = false;
static LCDMonitor::LCDState lcd_state;

// I2C slave configuration
static const uint8_t LCD_I2C_ADDRESS = 0x3C;
static bool i2c_slave_active = false;

// ---- Added: runtime emulator flag + remembered pins (no other behavior changed) ----
static volatile bool emulator_enabled = true;   // toggled by WiFiMgr via setEmulatorEnabled()
static int g_sda_pin = -1;
static int g_scl_pin = -1;

// HD44780 state
static uint8_t ddram_address = 0x00;

// HD44780 Commands
#define HD44780_CLEAR_DISPLAY     0x01
#define HD44780_RETURN_HOME       0x02
#define HD44780_ENTRY_MODE_SET    0x04
#define HD44780_DISPLAY_CONTROL   0x08
#define HD44780_CURSOR_SHIFT      0x10
#define HD44780_FUNCTION_SET      0x20
#define HD44780_SET_CGRAM_ADDR    0x40
#define HD44780_SET_DDRAM_ADDR    0x80

namespace LCDMonitor {

    // Forward declarations
    static void processHD44780Command(uint8_t cmd);
    static void processHD44780Data(uint8_t data);
    static void updateCursorPosition();
    static char translateHD44780Character(uint8_t code);

    static void ensureUdp() {
        if (!udp_begun) {
            lcdUdp.begin(LCD_MONITOR_UDP_PORT);
            udp_begun = true;
        }
    }

    // Simple ASCII character translation
    static char translateHD44780Character(uint8_t code) {
        // Only allow standard printable ASCII characters
        if (code >= 0x20 && code <= 0x7E) {
            return (char)code;
        }
        // Everything else becomes a space
        return ' ';
    }

    // Update cursor position from DDRAM address
    static void updateCursorPosition() {
        // PrometheOS uses these row offsets: { 0x00, 0x20, 0x40, 0x60 }
        if (ddram_address < 0x20) {
            lcd_state.cursor_row = 0;
            lcd_state.cursor_col = ddram_address;
        } else if (ddram_address >= 0x20 && ddram_address < 0x40) {
            lcd_state.cursor_row = 1;
            lcd_state.cursor_col = ddram_address - 0x20;
        } else if (ddram_address >= 0x40 && ddram_address < 0x60) {
            lcd_state.cursor_row = 2;
            lcd_state.cursor_col = ddram_address - 0x40;
        } else if (ddram_address >= 0x60 && ddram_address < 0x80) {
            lcd_state.cursor_row = 3;
            lcd_state.cursor_col = ddram_address - 0x60;
        } else {
            // Fallback
            lcd_state.cursor_row = 0;
            lcd_state.cursor_col = 0;
        }
        
        // Clamp to valid display area
        if (lcd_state.cursor_row >= 4) lcd_state.cursor_row = 3;
        if (lcd_state.cursor_col >= 20) lcd_state.cursor_col = 19;
    }

    // US2066/OLED I2C handler - PrometheOS protocol
    static void onI2CReceive(int numBytes) {
        Serial.printf("[LCD] RX: %d bytes\n", numBytes);
        
        // US2066 protocol: pairs of [control_byte, data_byte]
        while (Wire1.available() >= 2) {
            uint8_t control_byte = Wire1.read();
            uint8_t data_byte = Wire1.read();
            
            Serial.printf("[LCD] Control: 0x%02X, Data: 0x%02X\n", control_byte, data_byte);
            
            if (control_byte == 0x80) {
                // Command mode
                Serial.printf("[LCD] -> Command: 0x%02X\n", data_byte);
                processHD44780Command(data_byte);
            } else if (control_byte == 0x40) {
                // Data mode (character)
                Serial.printf("[LCD] -> Character: 0x%02X '%c'\n", data_byte, 
                             (data_byte >= 0x20 && data_byte <= 0x7E) ? (char)data_byte : '?');
                processHD44780Data(data_byte);
            } else {
                Serial.printf("[LCD] -> Unknown control: 0x%02X\n", control_byte);
            }
        }
        
        // Handle any remaining single byte (shouldn't happen in normal operation)
        if (Wire1.available() > 0) {
            uint8_t lone_byte = Wire1.read();
            Serial.printf("[LCD] WARNING: Lone byte: 0x%02X\n", lone_byte);
        }
        
        lcd_state.last_update_ms = millis();
    }

    // I2C slave request handler
    static void onI2CRequest() {
        uint8_t status = 0x00 | (ddram_address & 0x7F);
        Wire1.write(status);
        Serial.printf("[LCD] Status: 0x%02X\n", status);
    }

    // Process HD44780 command
    static void processHD44780Command(uint8_t cmd) {
        Serial.printf("[LCD] CMD: 0x%02X ", cmd);
        
        if (cmd == HD44780_CLEAR_DISPLAY) {
            for (int row = 0; row < 4; row++) {
                memset(lcd_state.rows[row], ' ', 20);
                lcd_state.rows[row][20] = '\0';
            }
            lcd_state.cursor_row = 0;
            lcd_state.cursor_col = 0;
            ddram_address = 0x00;
            Serial.println("(Clear)");
        }
        else if (cmd == HD44780_RETURN_HOME) {
            lcd_state.cursor_row = 0;
            lcd_state.cursor_col = 0;
            ddram_address = 0x00;
            Serial.println("(Home)");
        }
        else if ((cmd & 0x80) == HD44780_SET_DDRAM_ADDR) {
            ddram_address = cmd & 0x7F;
            updateCursorPosition();
            Serial.printf("(DDRAM: 0x%02X -> %d,%d)\n", ddram_address, 
                         lcd_state.cursor_row, lcd_state.cursor_col);
        }
        else if ((cmd & 0xF8) == HD44780_DISPLAY_CONTROL) {
            lcd_state.display_on = (cmd & 0x04) != 0;
            lcd_state.cursor_on = (cmd & 0x02) != 0;
            lcd_state.blink_on = (cmd & 0x01) != 0;
            Serial.printf("(Display: %s)\n", lcd_state.display_on ? "ON" : "OFF");
        }
        else {
            Serial.printf("(Other: 0x%02X)\n", cmd);
        }
    }
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
